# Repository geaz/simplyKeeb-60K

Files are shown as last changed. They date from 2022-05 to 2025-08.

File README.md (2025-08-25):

# simplyKeeb 60K family

This repository contains everything to build different variants of my 60 keys keyboard layout. The layout is designed with **10 finger typing, programmers & gamers** in mind.

The following variants are available at the moment:

- [simplyKeeb S60ph](printedmx) - *A completely 3D printed hotswap split keyboard*
- [simplyKeeb S60](splitmx) - *A pcb variant of the S60ph using a RP2040 and smd components*

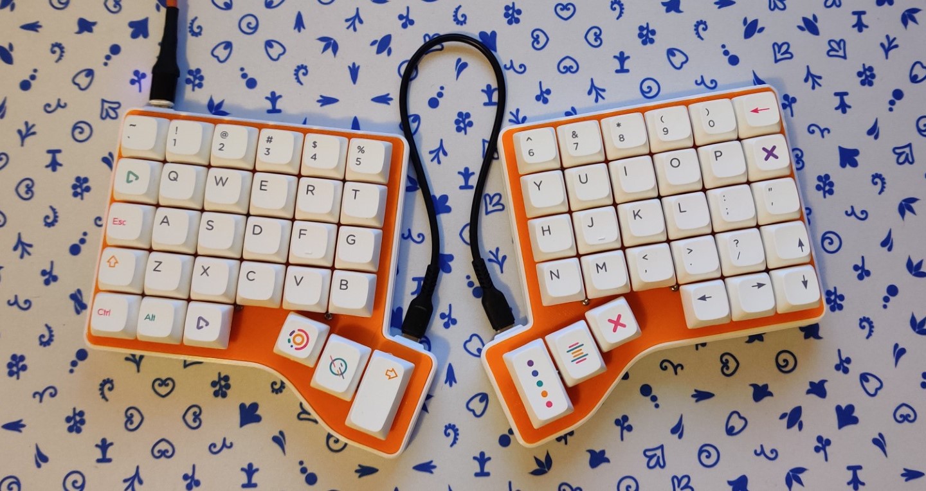
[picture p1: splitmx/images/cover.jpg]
simplyKeeb S60
|  |
|:--:|
| <b>simplyKeeb S60</b>|

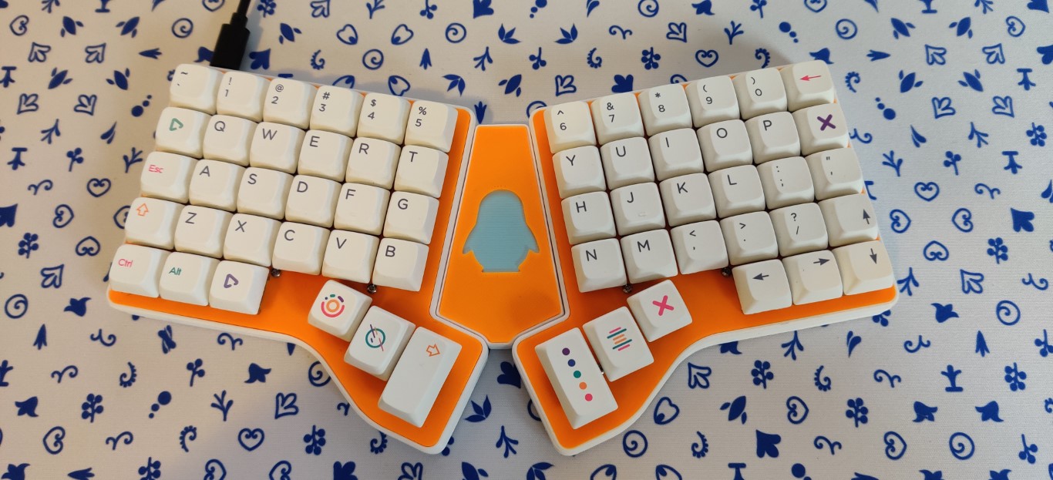
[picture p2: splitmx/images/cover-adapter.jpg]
simplyKeeb S60 with Adapter
|  |
|:--:|
| <b>simplyKeeb S60  with Adapter</b>|

## Layout

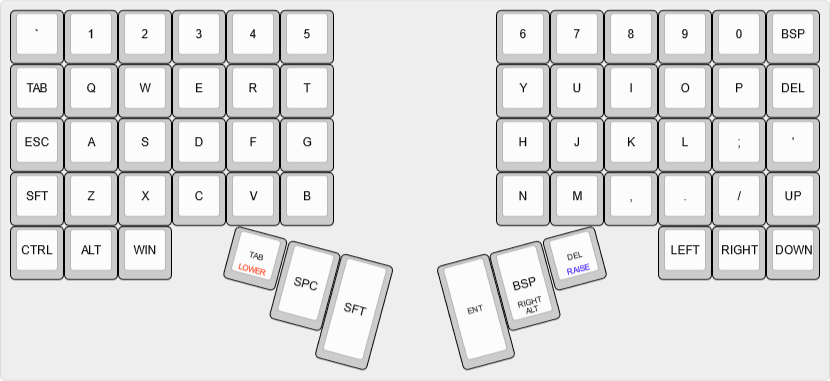
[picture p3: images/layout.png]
Layout


*Right Alt* is on a thumb key, because of german *Umlaute* like 'ä, ü & ö'. To use the *Backspace* in a repeating manner do a double tap and hold. This will trigger a repeating *backspace* instead of the hold key.

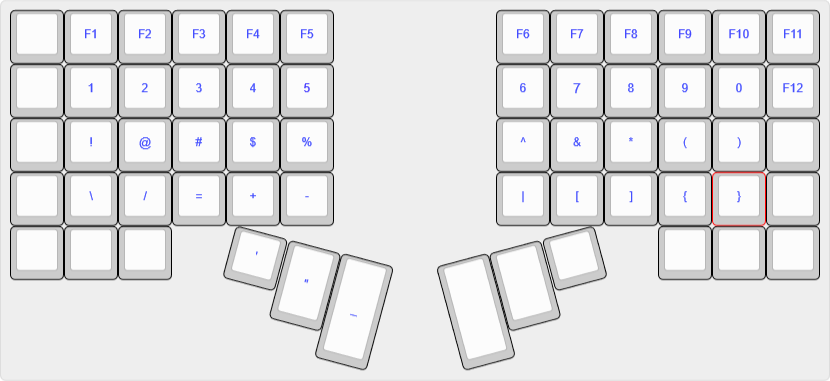
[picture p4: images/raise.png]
Raise

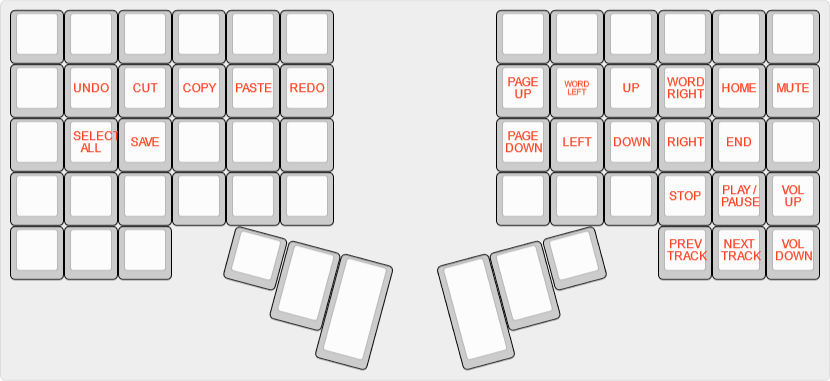
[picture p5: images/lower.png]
Lower


Please be aware, that the shortcuts on the keys are *Windows Shortcuts*. Many of them won't work on Linux or Mac OS.

## Firmware

To build the firmware, make sure you have a valid QMK firmware tool chain. Then execute the build.sh script in the firmware folder (the script expects the qmk at ~/qmk-firmware).

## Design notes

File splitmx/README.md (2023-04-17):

# simplyKeeb S60

This folder contains everything to build the **simplyKeeb S60**.

| simplyKeeb S60 |
|:--:|
| <b>simplyKeeb S60</b>|

| simplyKeeb S60 with Adapter |
|:--:|
| <b>simplyKeeb S60  with Adapter</b>|

## Features

- Split 
- 60 Keys with three key thumb clusters
- On Board SMD components
- RP2040
- USB C Connectors

## BOM

- Assembled PCB (produced by JLCPCB)
- 60x Hotswap Sockets
- 14x M2x12mm screws
- 14x M2x4mm Heat Set Inserts

## Adapter

Print all the parts from the **adapter** folder. If you want to change the cut out, you are free to edit the Fusion 360 model. Besides a modified usb type c cable, two M2 heat set inserts and two M2x5mm screws are needed.

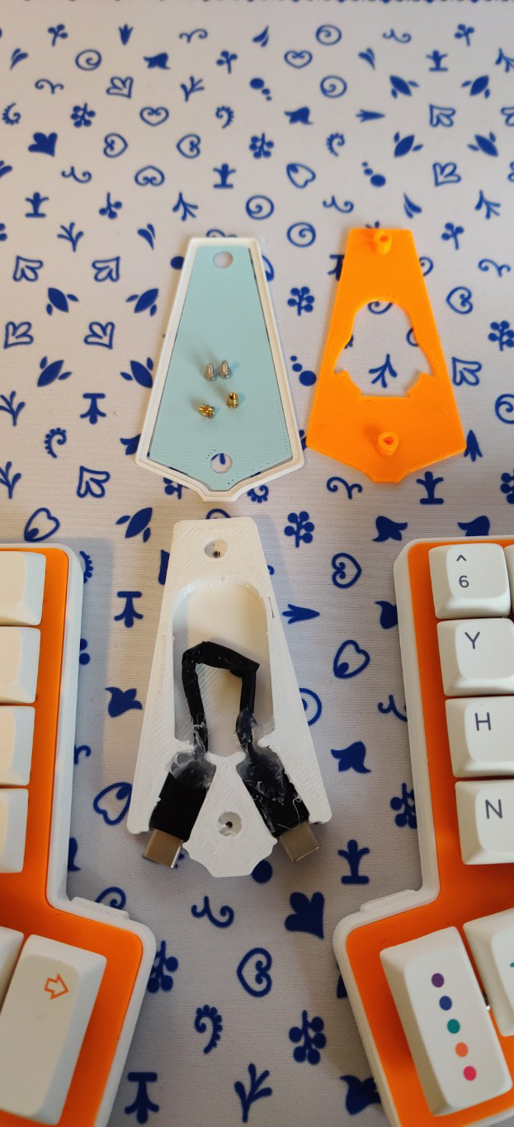
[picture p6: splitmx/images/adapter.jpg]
Adapter


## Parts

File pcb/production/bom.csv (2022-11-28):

Designator | Footprint | Quantity | Value | LCSC Part #
C1, C2 | C_0402_1005Metric | 2 | 30pF
C10, C8 | C_0402_1005Metric | 2 | 1uF | C92755
C11, C12, C13, C14, C15, C17, C18, C4, C6, C7, C9 | C_0402_1005Metric | 11 | 100nF | C83056
C16, C3, C5 | C_0402_1005Metric | 3 | 10uF
D10, D100, D106, D107, D108, D109, D110, D116, D117, D118, D119, D120, D16, D17, D18, D19, D20, D26, D27, D28, D29, D30, D36, D37, D38, D39, D40, D46, D47, D48, D49, D50, D56, D57, D58, D59, D6, D60, D61, D62, D63, D64, D65, D7, D71, D72, D73, D74, D75, D8, D86, D87, D88, D89, D9, D90, D96, D97, D98, D99 | D_SOD-123 | 60 | 1N4148W
R1, R4 | R_0402_1005Metric | 2 | 5.1k
R10, R3 | R_0402_1005Metric | 2 | 10k
R2, R5 | R_0402_1005Metric | 2 | 1k
R6, R7 | R_0402_1005Metric | 2 | 27R | C25100
R8, R9 | R_0402_1005Metric | 2 | R4.7k
SW1, SW2 | SW-SMD_L6.0-W3.3-LS8.0 | 2 | ~
SW10, SW11, SW12, SW13, SW14, SW15, SW16, SW17, SW18, SW19, SW20, SW21, SW22, SW23, SW24, SW25, SW26, SW28, SW29, SW3, SW30, SW31, SW33, SW34, SW35, SW36, SW38, SW39, SW4, SW40, SW41, SW43, SW44, SW45, SW46, SW47, SW48, SW49, SW5, SW50, SW51, SW52, SW53, SW54, SW55, SW56, SW57, SW58, SW59, SW6, SW60, SW61, SW62, SW7, SW8, SW9 | MXOnly-1U-Hotswap | 56 | SW_Push
SW27, SW42 | MXOnly-1.5U-Hotswap-Vertical | 2 | SW_Push
SW32, SW37 | MXOnly-2U-Hotswap-Vertical | 2 | SW_Push
U1 | SOIC-8_L5.3-W5.3-P1.27-LS8.0-BL | 1 | ~ | C82317
U10 | TSSOP-24_L7.8-W4.4-P0.65-LS6.4-BL | 1 | PCA9555PW (IO Expander) | C128392
U2 | SOT-223-3_L6.5-W3.4-P2.30-LS7.0-BR | 1 | ~ | C26537
U3 | RP2040 | 1 | ~ | C2040
USB1, USB2, USB3 | USB-C-SMD_TYPE-C-31-M-31 | 3 | USB Type C | C2760486
X1 | CRYSTAL-SMD_L7.4-W4.0-LS8.0 | 1 | S4T12000ZYFAC | C2149004

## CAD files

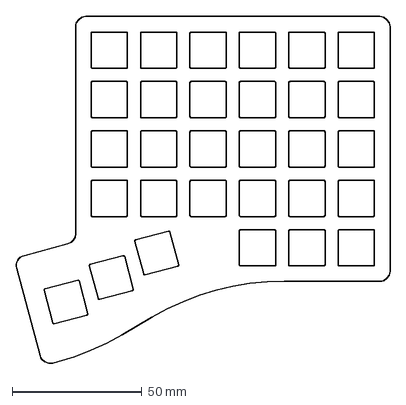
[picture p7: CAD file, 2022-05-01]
printedmx/keeb/plate.dxf
144.2 x 134.2 mm

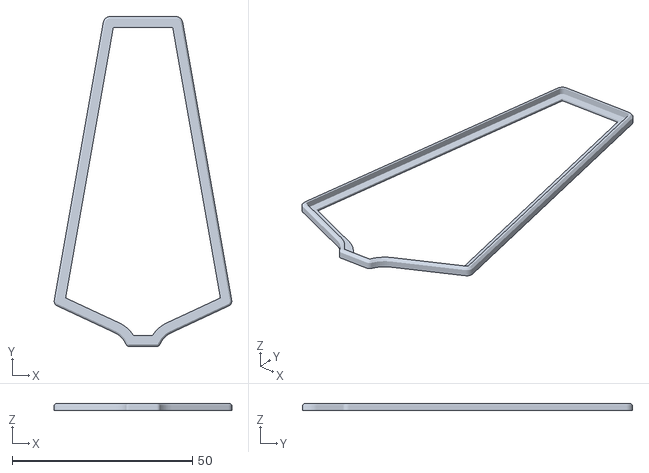
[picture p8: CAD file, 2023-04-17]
splitmx/adapter/Top.stl
49.2 x 91.5 x 2.00

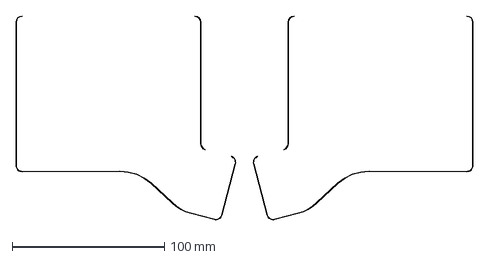
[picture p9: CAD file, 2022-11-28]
splitmx/cad/pcb.dxf
300.0 x 133.9 mm

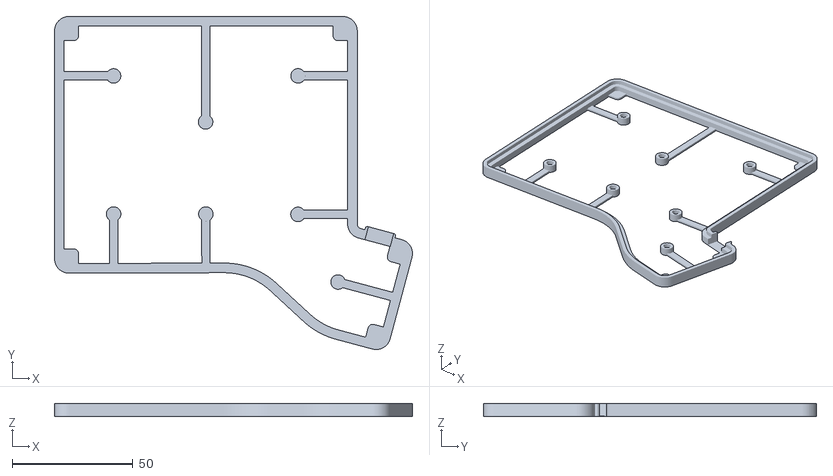
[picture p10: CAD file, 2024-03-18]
splitmx/stl/Alternate Slim Bottom (MIRROR IT).stl
148.1 x 137.8 x 5.20

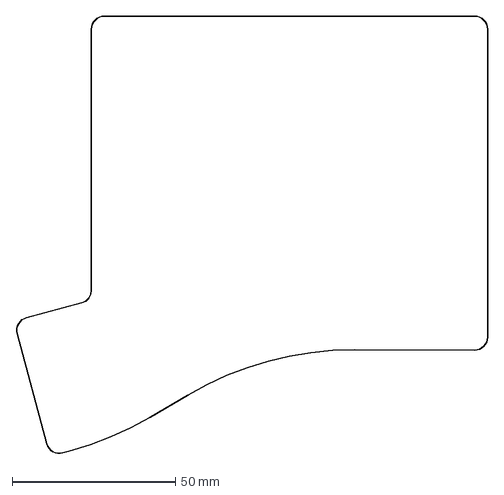
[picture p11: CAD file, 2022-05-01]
printedmx/keeb/outline.dxf
144.2 x 134.2 mm

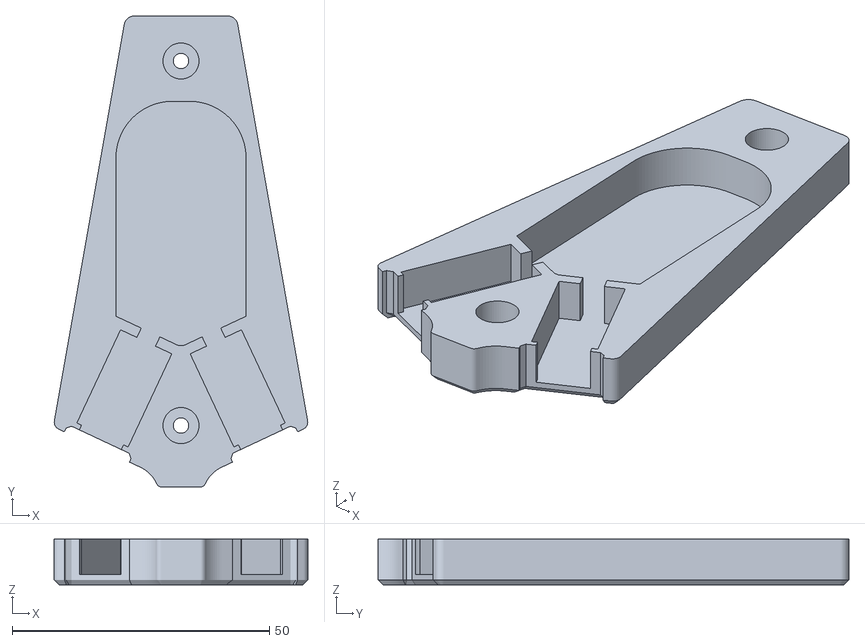
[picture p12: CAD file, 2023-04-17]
splitmx/adapter/Bottom.stl
49.2 x 91.5 x 8.90

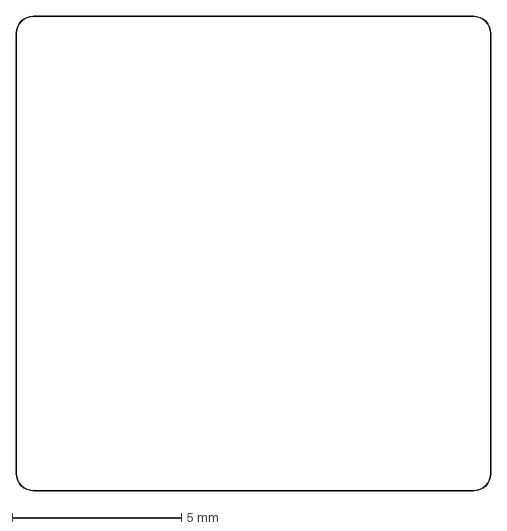
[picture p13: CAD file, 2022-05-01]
printedmx/keeb/hole.dxf
14.0 x 14.0 mm

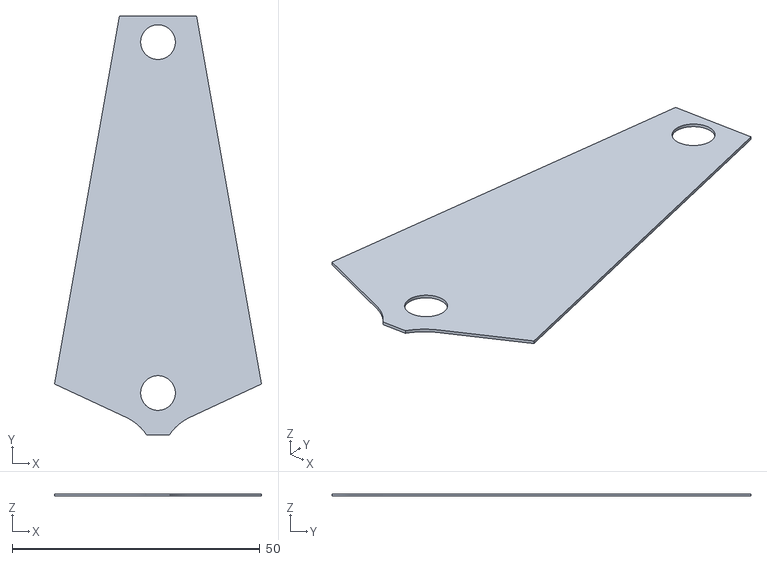
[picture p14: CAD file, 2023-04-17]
splitmx/adapter/Inlay.stl
41.8 x 84.5 x 0.5

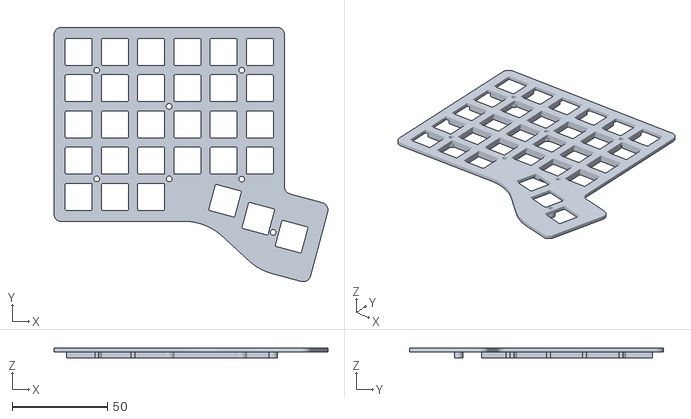
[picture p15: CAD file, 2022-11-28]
splitmx/stl/Plate.stl
144.1 x 133.8 x 5.00

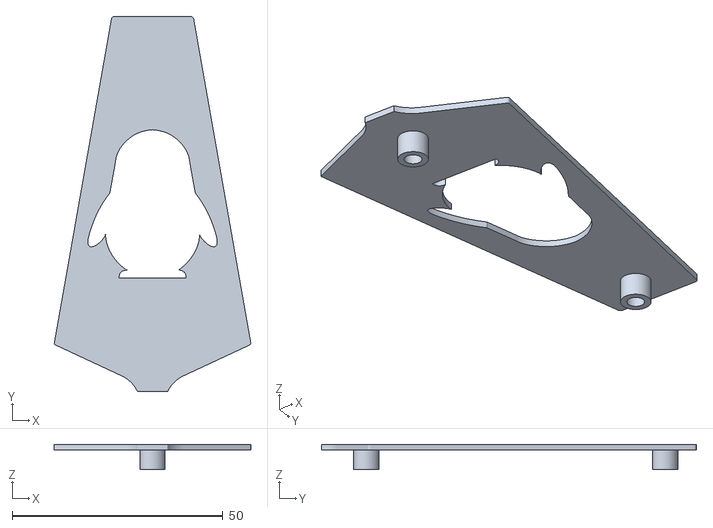
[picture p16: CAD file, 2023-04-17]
splitmx/adapter/Top Inlay.stl
46.6 x 88.9 x 6.00

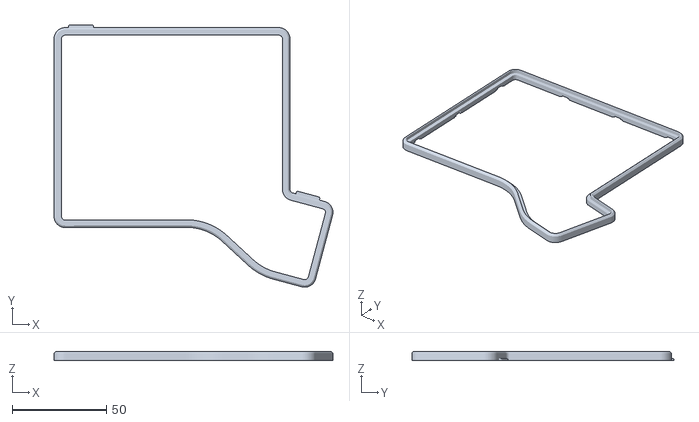
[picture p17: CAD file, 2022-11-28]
splitmx/stl/Top.stl
148.1 x 139.3 x 5.00

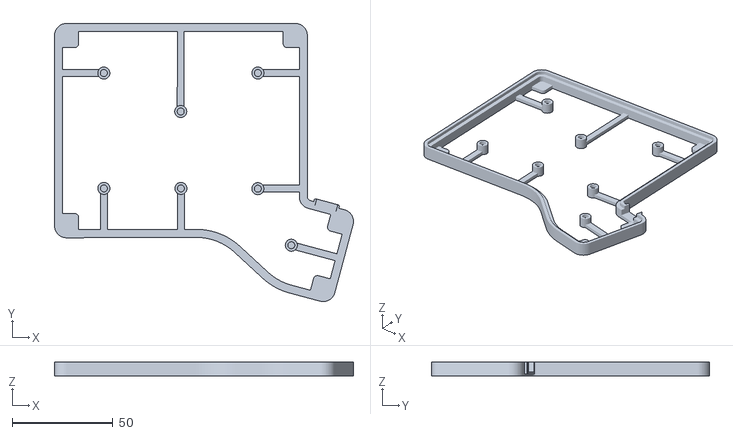
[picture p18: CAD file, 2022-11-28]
splitmx/stl/Bottom (MIRROR IT).stl
148.1 x 137.8 x 7.10

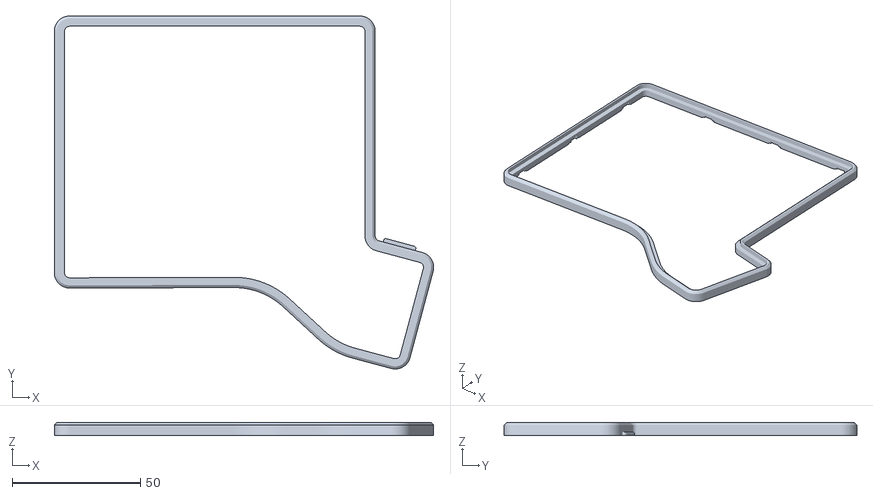
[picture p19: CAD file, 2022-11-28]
splitmx/stl/Top (MIRROR IT).stl
148.1 x 137.8 x 5.00

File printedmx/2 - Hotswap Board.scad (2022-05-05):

include <keeb/positions.scad>
include <0 - Variables.scad>

difference(){
    union(){
        difference(){
            linear_extrude(hsBoardHeight)
            import("keeb/outline.dxf");

            linear_extrude(hsBoardHeight)
            offset(-hsSocketInsetSize)
            import("keeb/outline.dxf");
        }
        
        translate([0,0,hsBoardHeight - hsSocketRestHeight])
        linear_extrude(hsSocketRestHeight)
        offset(-hsSocketInsetSize)
        import("keeb/plate.dxf");

        linear_extrude(hsBoardHeight - hsSocketRestHeight)
        import("keeb/plate.dxf");
    }

    genScrewHoles();
}

module genScrewHoles(){
    for(screw = screwPositions){
        translate([screw[0],screw[1],0])
        linear_extrude(hsBoardHeight)
        circle(d = screwHoleDiameter);
    }
}

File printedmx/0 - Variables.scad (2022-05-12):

$fn = 64;

switchHoleClearance =       0.1; // Widens the switch plate holes by the given amount.
printClearance =            0.2; // Clearance necessary for printed parts to fit better. Used for points where one printed part is inserted in another one.

smallSocketClearance =      0.7; // Hotswap Socket Clearance for holes below a size of 1.5mm. 
                                 // Because 3d printers are not that accurate at this size, it is necessary to have a bigger clearance.
                                 // Recommended: "printClearance + Line Width (Slicer)" for PETG it may be necessary to add even more clearance, because of the material expansion.

//
// It should not be necessary to edit one of the followin variables:
//

mxSize =                    14;
mxDistanceToBoard =         5;

pinThicknessR =             0.5   + smallSocketClearance;
pinThicknessL =             0.3   + smallSocketClearance;
pinWidth =                  1.2   + smallSocketClearance;

socketSize =                16;
socketHeight =              2;
switchSocketDia =           4.2   + printClearance;
switchPinsDia =             1.5   + smallSocketClearance;

diodeWidth =                4     + printClearance;
diodeThickness =            2     + printClearance;
diodeWireDia =              0.4   + smallSocketClearance;

restInsetSize =             1     + printClearance;

hsBoardHeight =             1.5;
hsSocketInsetSize =         (socketSize - mxSize)/2 + printClearance;
hsSocketRestHeight =        1;
hsBoardRestHeight =         hsBoardHeight + printClearance;

plateHeight =               2;
plateRestHeight =           plateHeight + printClearance;

topLayerHeight =            mxDistanceToBoard + (socketHeight - hsSocketRestHeight);
middleLayerHeight =         4;
bottomLayerHeight =         6.5;
wallThickness =             3;
floorHeight =               1.5;

bottomLayerScrewHeight =    bottomLayerHeight+middleLayerHeight-hsBoardHeight;

ledRestHeight =             1;
ledRestWidth =              10    + printClearance;

trrsWidth =                 6     + printClearance;
trrsLength =                12.1  + printClearance;
trrsHeight =                5     + printClearance;
trrsSlotThickness =         1;

proMicroWidth =             19    + printClearance;
proMicroLength =            34    + printClearance;
proMicroThickness =         2     + printClearance;
proMicroSlotDepth =         1.5;
proMicroSlotZOffset =       2;
proMicroSlotThickness =     3;
proMicroScrewDiameter =     2.5   + printClearance;

usbWidth =                  10    + printClearance;
usbHeight =                 3.5   + printClearance;

screwHoleDiameter =         3;
screwInsertDiameter =       3.2;
screwPlatePostDiameter =    5;
screwPostDiameter =         6;

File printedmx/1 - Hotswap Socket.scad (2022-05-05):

include <0 - Variables.scad>

genSocket();

module genSocket() {
    difference(){
        // Socket
        linear_extrude(socketHeight)
        offset((socketSize - mxSize)/2)
        import("keeb/hole.dxf");
        
        // Wire Slots
        translate([-socketHeight, 5, 1])
        linear_extrude(1)
        square([9, diodeWireDia], center = true);
        
        translate([-5.25, 2.5, 1])
        linear_extrude(1)
        square([2.5, diodeWireDia], center = true);
        
        // Wire Holes
        linear_extrude(socketHeight)
        translate([-6.5, 2.5, 0])
        circle(d = diodeWireDia); 
        
        linear_extrude(socketHeight)
        translate([-6.5, 5, 0])
        circle(d = diodeWireDia);
        
        // Diode Hole
        linear_extrude(socketHeight)
        translate([-3, 5, 0])
        square([diodeWidth, diodeThickness], center = true);
        
        linear_extrude(socketHeight)
        gen2dSwitchFootprint();
    }
}

module gen2dSwitchFootprint(){
    translate([-5, 0, 0])
    circle(d = switchPinsDia);

    translate([5, 0, 0])
    circle(d = switchPinsDia);

    circle(d = switchSocketDia);

    translate([-3.8, 2.5, 0])
    gen2dPinHole(pinThicknessL);

    translate([2.5, 5, 0])
    gen2dPinHole(pinThicknessR);
}

module gen2dPinHole(pinThickness){
    midPoint = pinWidth/2 - pinThickness/2;

    // Center the hole
    translate([-pinWidth/2 + pinThickness/2, 0, 0]) {
        translate([midPoint, 0, 0])
        square([pinWidth - pinThickness, pinThickness], center = true);

        circle(d = pinThickness);

        translate([pinWidth - pinThickness, 0, 0])
        circle(d = pinThickness);
    }
}

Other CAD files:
splitmx/stl/Alternate Slim Bottom.stl
splitmx/stl/Bottom.stl
printedmx/3 - Plate.scad
printedmx/4 - Top Layer.scad
printedmx/5 - Middle Layer.scad
printedmx/6 - Bottom Layer.scad
printedmx/7 - Pro Micro Mount.scad
printedmx/keeb/positions.scad
splitmx/cad/plate.dxf

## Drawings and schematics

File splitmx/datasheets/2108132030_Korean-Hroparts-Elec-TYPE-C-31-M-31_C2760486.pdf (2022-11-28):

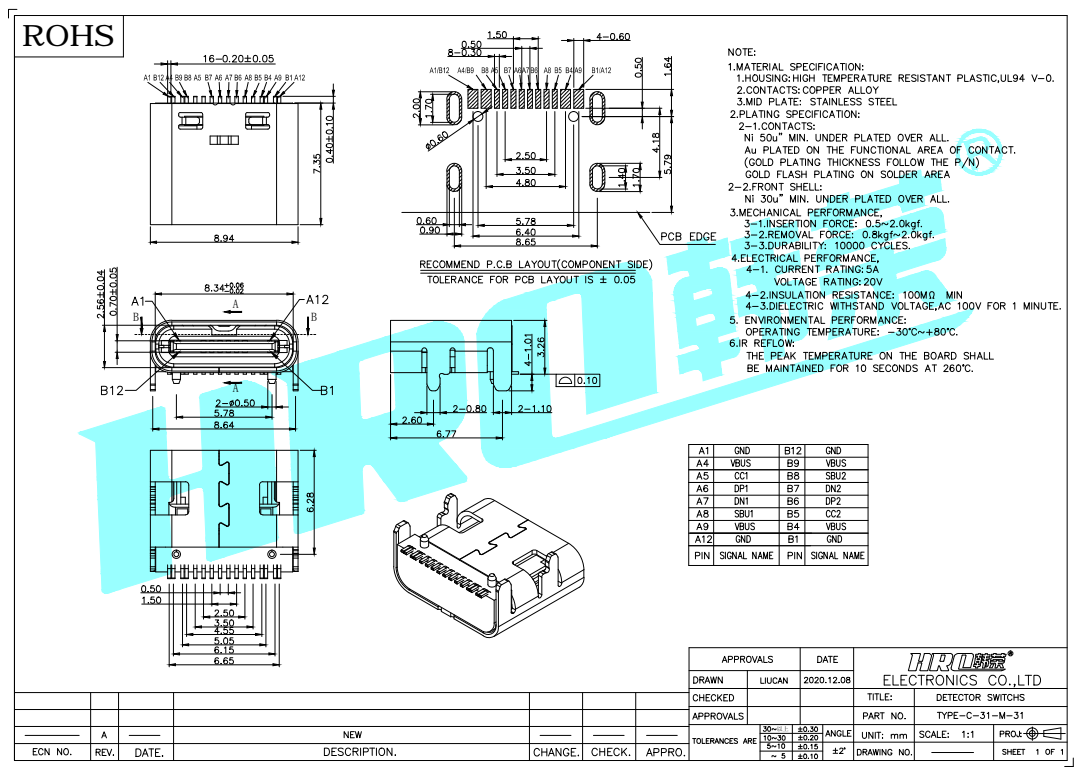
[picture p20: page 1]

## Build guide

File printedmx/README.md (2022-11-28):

# simplyKeeb S60ph

This folder contains everything to generate, print and build the **simplyKeeb S60ph** (splitted 60 keys, printed hotswap).
The keyboard models are automatically generated out of a few dxf files.  
**It is completely 3D printable! Including the hotswap sockets.**

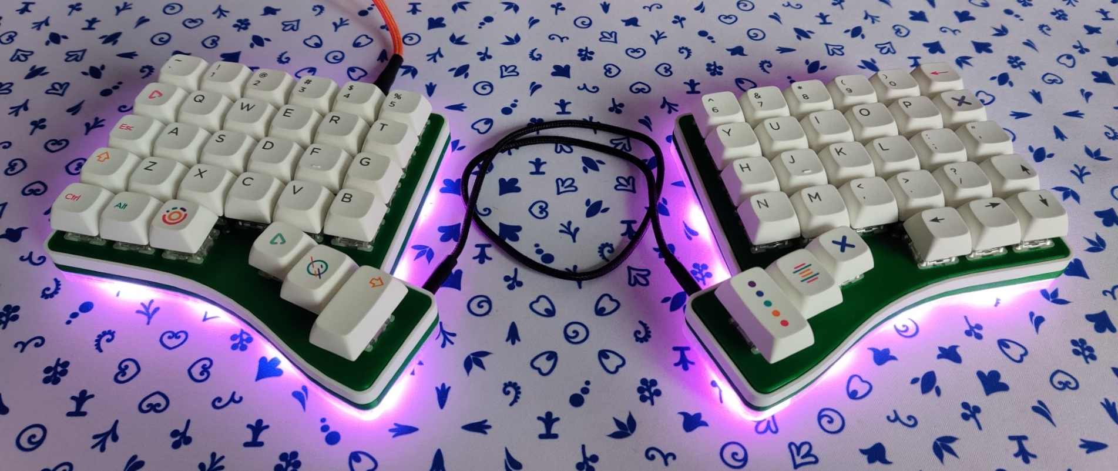
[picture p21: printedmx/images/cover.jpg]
simplyKeeb S60ph


## Features

- Split 
- 60 Keys with three key thumb clusters
- RGB Backlight
- Completly 3D printable

## Flaws

- No reset button

## FAQ

**Q >** Do you recommend building this keyboard?  
**A >** No! I really love the layout, but the build of the printed hot swaps was a very tedious task! The keyboard is great, if done, but please bear in mind, that it is by no means an enjoyable build!

**Q >** Why do you use individual hotswap sockets that then have to be welded together? Instead of printing the complete hotswap board directly?  
**A >** Because of the tight tolerances of the sockets. By printing them individually you are able to sort out single sockets, if the tolerances of some sockets are not perfect. Otherwise you would be forced to reprint a whole board!

**Q >** To many keys! I just use four! Learn to use layers!  
**A >** I already own and use 36 key keyboards, but I wanted a layout which is useable for any task I face and which is suitable for gaming.

## BOM

- Printed Parts
- 60x Diodes
- 2x Pro Micro
- 2x TRRS
- 2x M3x5mm scews
- 14x M2x12mm screws
- 14x M2x4mm Heat Set Inserts
- LEDs, if you want a backlight

## Prerequisites

This version uses [OpenSCAD](https://openscad.org/) to generate the 3D printable files. Please make sure, that you have installed the latest version. If you want to automatically build all STLs, you should also install *python*.

## Generate and print the models

To generate the 3D models just execute the *build.py* and enter the necessary information.

Before printing all parts, it is advisable to test if the tolerances for the hotswap sockets fit. Simply print one or two of the sockets and build them as described below. If everything fits, the remaining sockets and parts can be printed.

## Build the keyboard

**Please be aware, that I will not describe the full build of the electronics. This chapter only describes parts of the build necessary to understand how the 3D printed parts are meant to be used. If your don't know how to handwire a keyboard, please look into one of the already available great tutorials out there.**

### Hotswap Socket

To build one hotswap socket you need one of the printed sockets and one diode.

1. Bend the legs of the diode and insert it into the upper holes of the socket. 

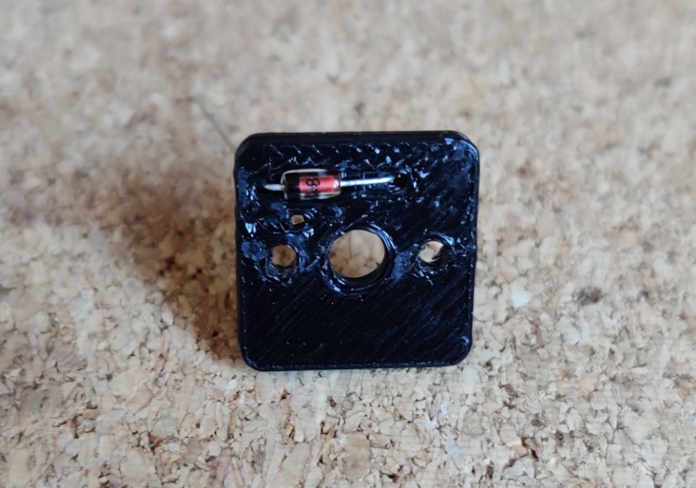
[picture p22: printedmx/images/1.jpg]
Socket 1


2. Cut the leg on the right (top view). Not flush to the socket! Leave a bit of the leg like in the picture.

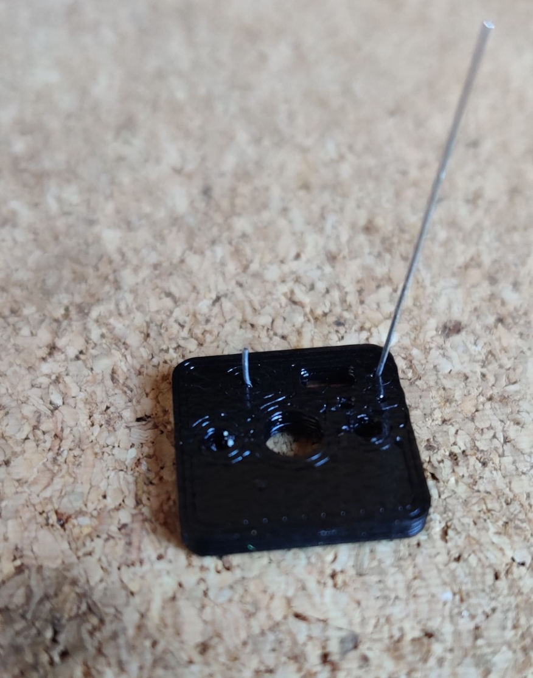
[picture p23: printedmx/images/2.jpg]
Socket 2


3. Bend the cut leg. Picture for reference.

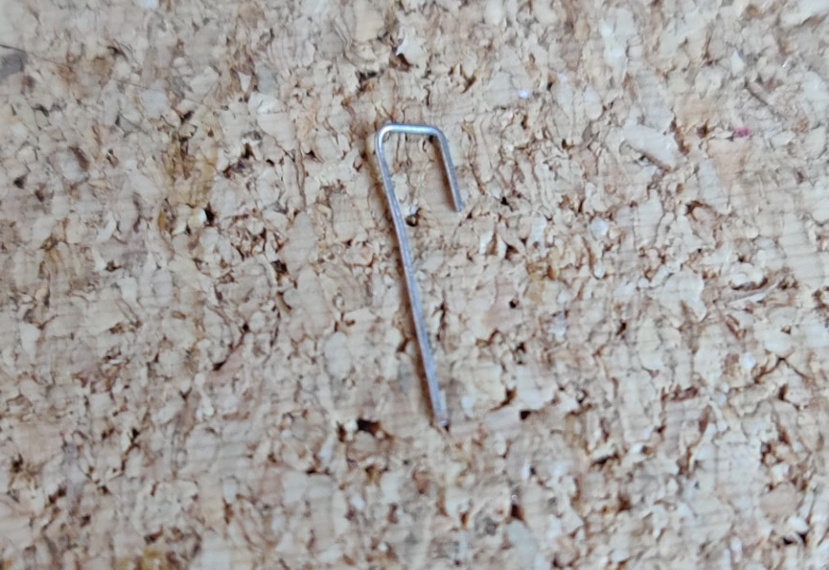
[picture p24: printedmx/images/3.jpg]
Socket 3


4. Insert the leg into the bottom holes of the socket. Short end to the right.

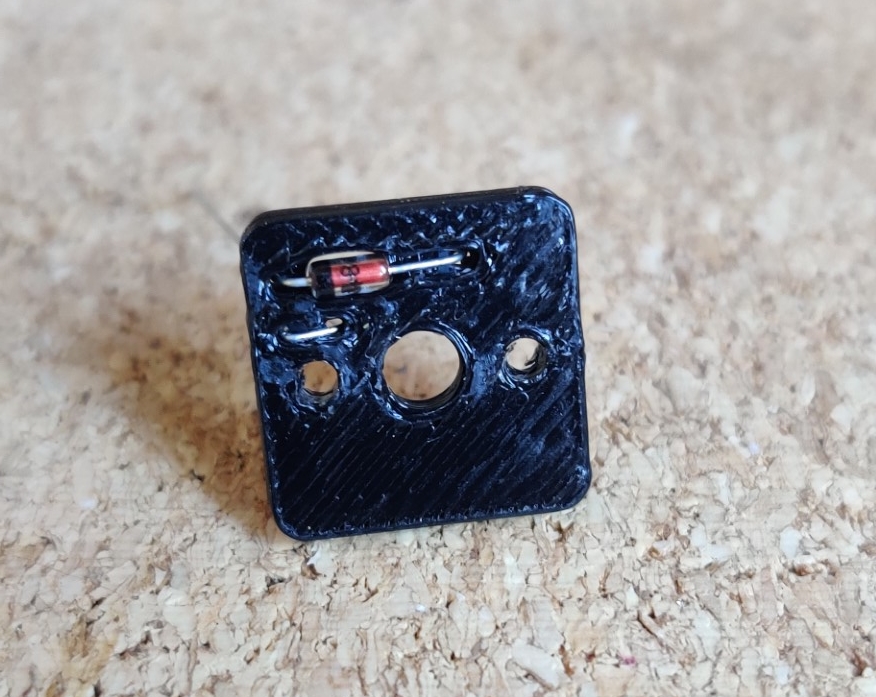
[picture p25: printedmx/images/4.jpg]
Socket 4


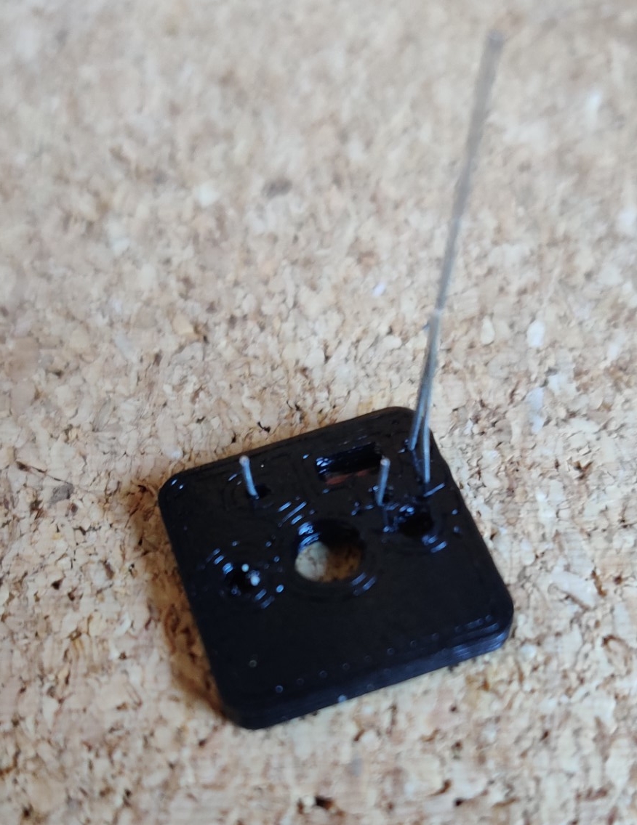
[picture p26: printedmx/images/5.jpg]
Socket 5


5. Insert a switch and bend the short ends to prevent them from slipping out of the holes.

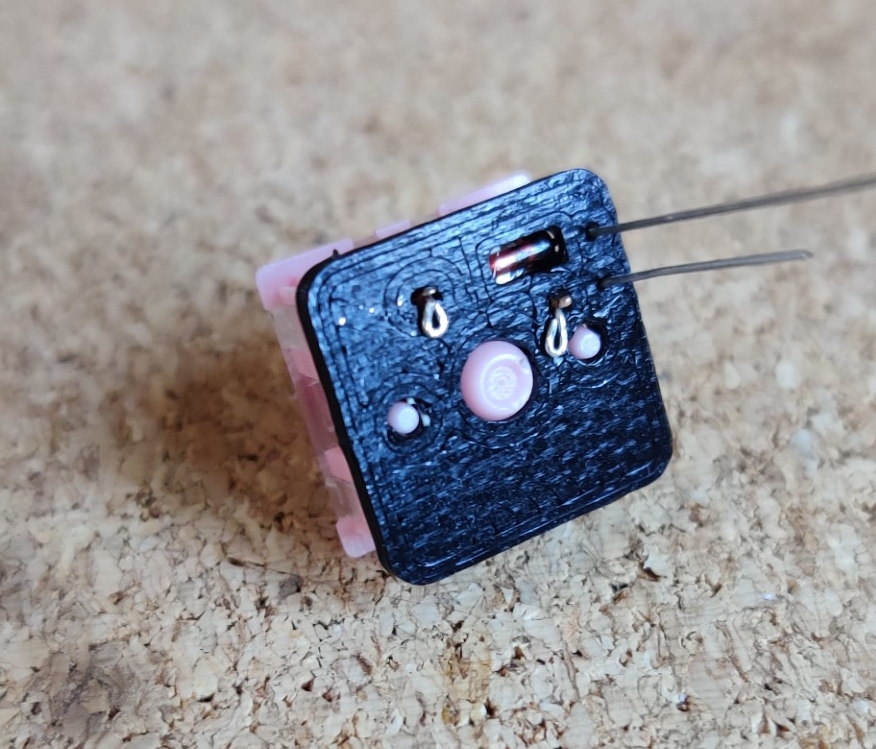
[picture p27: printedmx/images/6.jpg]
Socket 6


You successfully created a printed hotswap socket! If you want to make sure it works, just take a digital multimeter and test it in diode mode.

### Hotswap Board

In this step the hotswap board will be put together. You need all of your build hotswap sockets, the hotswap boards and an old soldering tip. Insert the hotswap socket into the board, heat up your soldering iron to 240°C and weld the socket and the board together. Repeat this for all sockets.

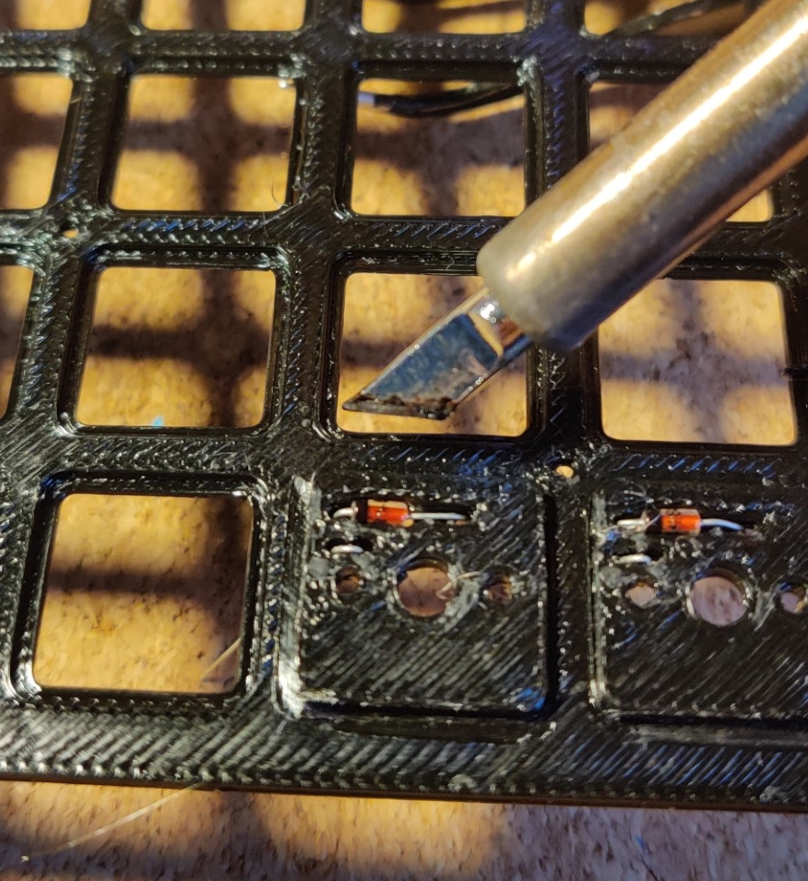
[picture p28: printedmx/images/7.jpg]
Board 7


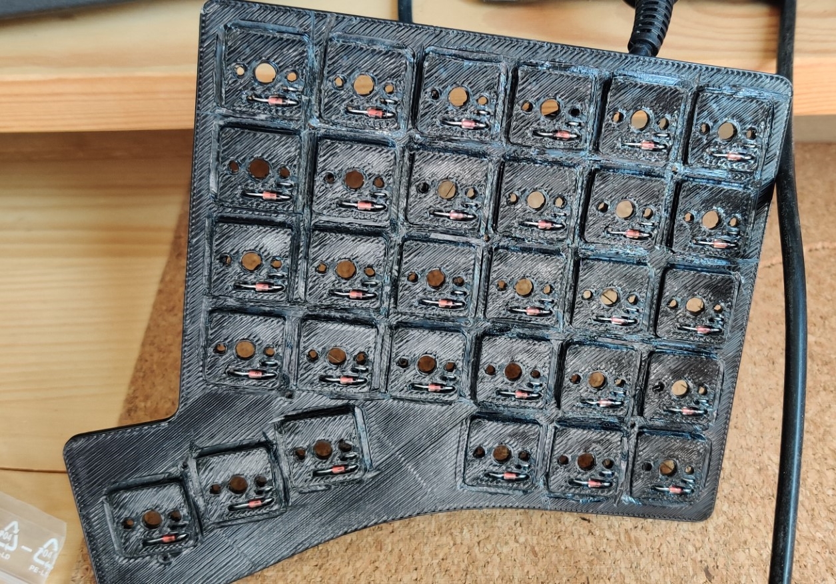
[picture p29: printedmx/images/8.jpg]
Board 8


### Case

Following a few pictures of the remaining build. The remaining parts should be straight forward, if you know how to do a handwired build.

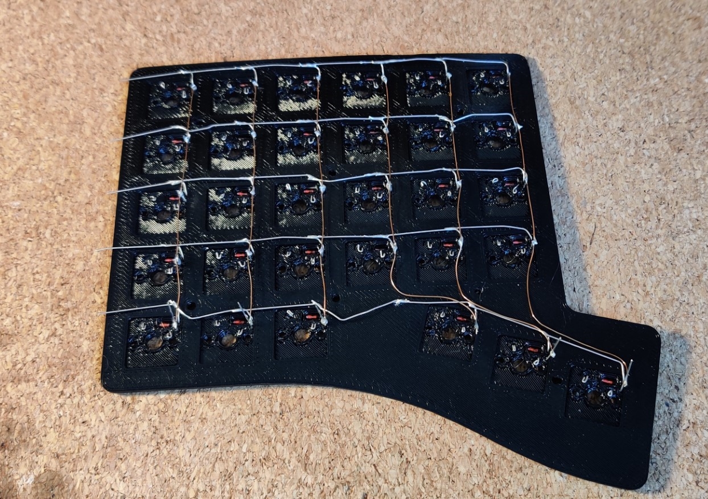
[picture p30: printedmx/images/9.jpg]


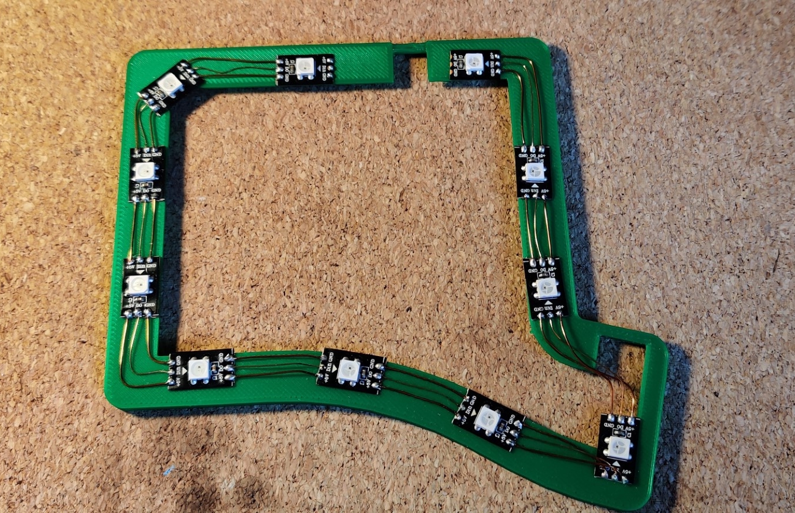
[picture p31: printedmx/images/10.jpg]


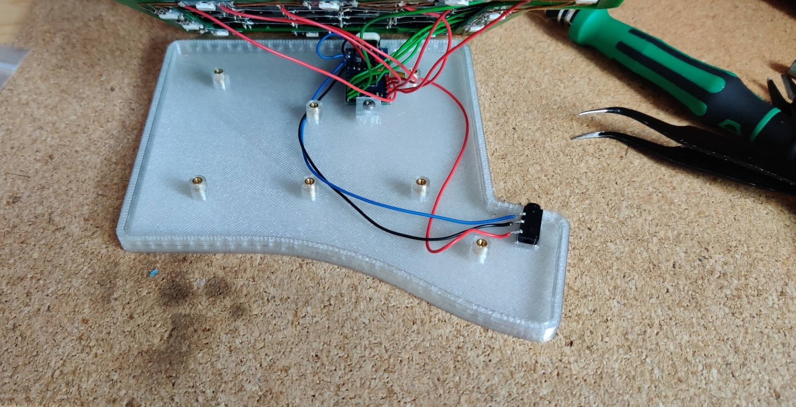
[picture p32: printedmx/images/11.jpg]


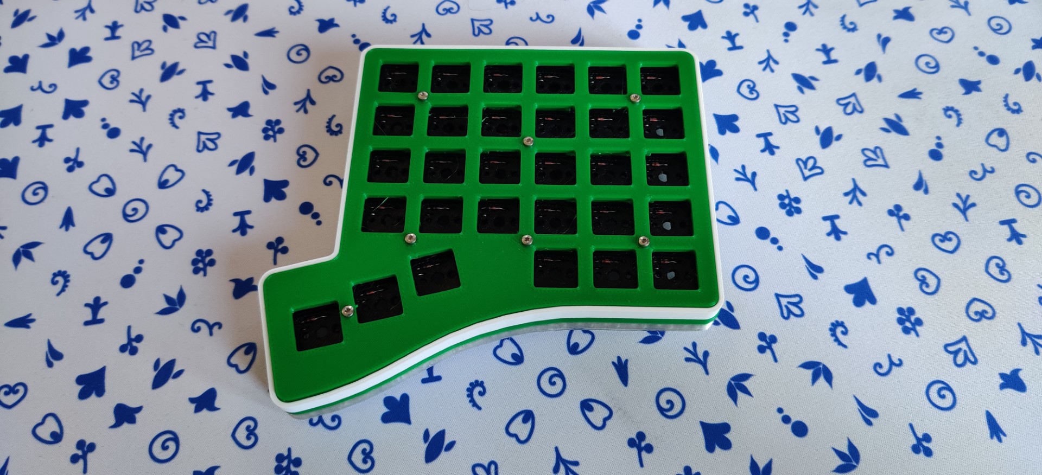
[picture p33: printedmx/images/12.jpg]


## Using the OpenSCAD files to generate a custom layout

The OpenSCAD models are completly configurable by a few files in the *keeb* folder:

- **plate.dxf** *The plate outline including the switch positions*
- **outline.dxf** *The plate outline without the switch positions*
- **hole.dxf** *The outline of a single switch. This is necessary to generate the right shape for the hotswap sockets.*
- **positions.scad** *Contains the position of the screws, pro micro and trrs (if needed).*

By changing these files, it is possible to create a custom keyboard! For example:

- Head over to the [Keyboard Layout Editor](http://www.keyboard-layout-editor.com/) and create a layout you like. Save the raw data.
- Head over to the [ai03 plate generator](https://kbplate.ai03.com/) and paste the raw data from step one. Download the generated dxf file and save it as **plate.dxf**.  
- Create the *hole.dxf* and *outline.dxf* out of the generated *plate.dxf*. (use *libreCAD* for example)
- Replace the files in the *keeb* folder and change the *positions.scad* to suite your layout
- Run the *build.py* and enjoy your custom layout

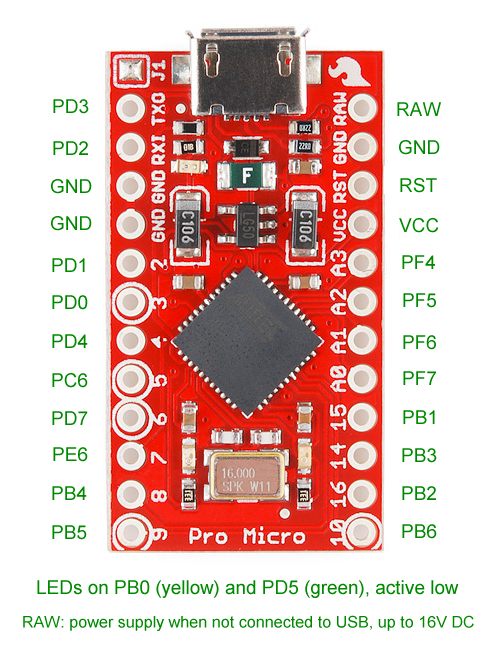
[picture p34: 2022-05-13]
printedmx/images/promicro-pins.png

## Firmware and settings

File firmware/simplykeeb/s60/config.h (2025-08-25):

#pragma once

// I2C Configuration for the RP2040
// QMK Implementation does not allow definition of I2C0 PINS!
// Always taking the I2C1 pins, regardlesss of used driver...
#define I2C_DRIVER I2CD0
#define I2C1_SDA_PIN GP0
#define I2C1_SCL_PIN GP1

// RIGHT_HALF PCA9555 address
#define RIGHT_HALF 0b0100000

// Matrix Definitions
#define MATRIX_ROWS  5
#define MATRIX_COLS  12
#define MATRIX_ROWS_PER_SIDE MATRIX_ROWS
#define MATRIX_COLS_PER_SIDE (MATRIX_COLS / 2)

#define MATRIX_ROW_PINS_L { GP18, GP19, GP20, GP21, GP22 }
#define MATRIX_COL_PINS_L { GP23, GP24, GP6, GP5, GP4, GP7 }

#define MATRIX_ROW_PINS_R { 0b00000001, 0b00000010, 0b00000100, 0b00001000, 0b00010000 }
#define MATRIX_COL_PINS_R { 0b00000001, 0b00000010, 0b00000100, 0b00001000, 0b00010000, 0b00100000 }

// Bootloader Config
#define RP2040_BOOTLOADER_DOUBLE_TAP_RESET
#define RP2040_BOOTLOADER_DOUBLE_TAP_RESET_TIMEOUT 200U

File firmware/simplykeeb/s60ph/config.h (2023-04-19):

#pragma once

#include "config_common.h"

#define VENDOR_ID    0x1410
#define PRODUCT_ID   0x0001
#define DEVICE_VER   0x0001
#define MANUFACTURER simplyKeeb
#define PRODUCT      s60HK

#define MATRIX_ROWS  10
#define MATRIX_COLS  6
#define MATRIX_ROW_PINS \
    { C6, D7, E6, B4, B5 }

#define MATRIX_COL_PINS \
    { F6, F7, B1, B3, B2, B6 }

#define DEBOUNCE 5

#define USE_SERIAL
#define SOFT_SERIAL_PIN D2
#define DIODE_DIRECTION COL2ROW

#define RGB_DI_PIN D3
#define RGBLED_NUM 22
#define RGBLIGHT_SPLIT
#define RGBLED_SPLIT { 11, 11 }
#define RGBLIGHT_EFFECT_RAINBOW_MOOD

#define BOOTMAGIC_LITE_ROW 0
#define BOOTMAGIC_LITE_COLUMN 1
#define BOOTMAGIC_LITE_ROW_RIGHT 4
#define BOOTMAGIC_LITE_COLUMN_RIGHT 1

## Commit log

2022-05-01 Update 5 - Middle Layer.scad
    [5 - Middle Layer.scad]
2022-05-01 Fix top layer height and plate rests
    [0 - Variables.scad, 4 - Top Layer.scad, 5 - Middle Layer.scad]
2022-05-01 Some fixes and add license
    [0 - Variables.scad, 5 - Middle Layer.scad, 6 - Bottom Layer.scad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]
2022-05-01 Fix some errors
    [0 - Variables.scad, 3 - Plate.scad, 5 - Middle Layer.scad]
2022-05-02 Change pro micro mount and fix plate
    [0 - Variables.scad, 3 - Plate.scad, 6 - Bottom Layer.scad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]
2022-05-05 Change to Screw Inserts and a few fixes
    [0 - Variables.scad, 1 - Hotswap Socket.scad, 2 - Hotswap Board.scad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]
2022-05-09 Changed screw holes to heat inserts
    [0 - Variables.scad]
2022-05-12 Add params file during build
    [0 - Variables.scad]
2022-11-28 Add S60 variant
    [0 - Variables.scad, 1 - Hotswap Socket.scad, 2 - Hotswap Board.scad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]
2023-04-17 Add split adapter (#1)
    [Bottom.stl, Inlay.stl, Top Inlay.stl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]
2024-03-18 Higher debounce and new bottom STL (#2)
    [Alternate Slim Bottom (MIRROR IT).stl, Alternate Slim Bottom.stl]
